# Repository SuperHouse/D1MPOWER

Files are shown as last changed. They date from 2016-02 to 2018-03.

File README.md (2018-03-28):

Power Shield for the WeMos D1 Mini
==================================

Copyright 2016 SuperHouse Automation Pty Ltd  www.superhouse.tv  

Power supply expansion shield for the [WeMos D1 Mini][1], which is a microcontroller board based on the ESP8266 module.

Features:

 * 2.1mm DC jack and screw terminal connections for power input.
 * 5Vdc output, max 800mA.
 * 7-14Vdc nominal input range, 20Vdc max input.
 * Input polarity protection.
 * Power LED.
 * Filter caps.

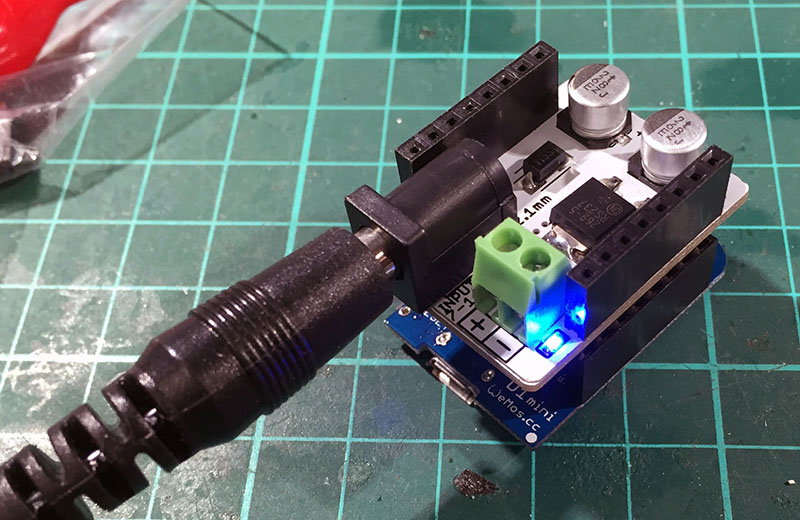
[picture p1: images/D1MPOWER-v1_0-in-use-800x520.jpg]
Oblique view 1


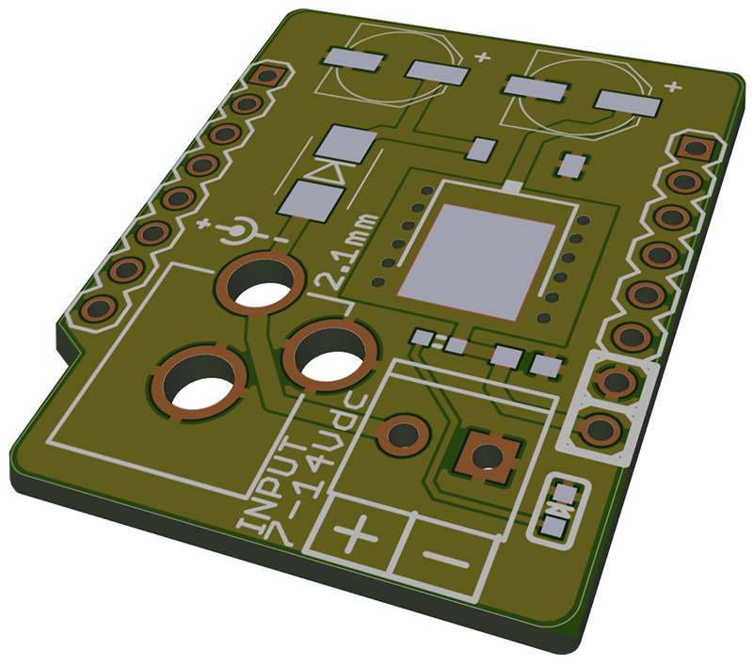
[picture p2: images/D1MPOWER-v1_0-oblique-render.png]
Oblique view 2


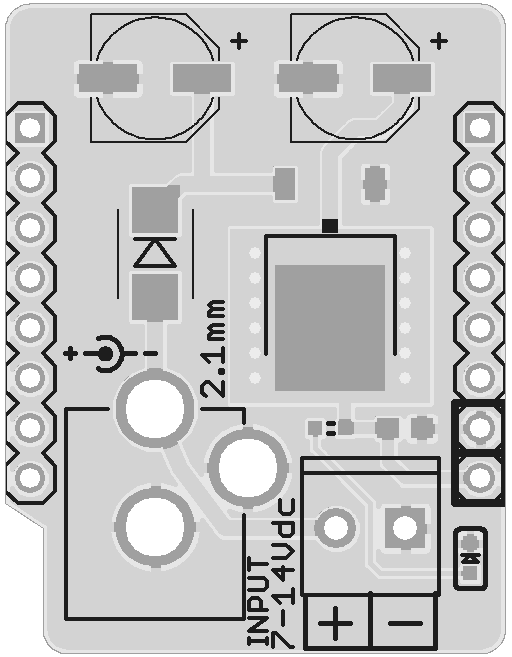
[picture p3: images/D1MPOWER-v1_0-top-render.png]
Top view


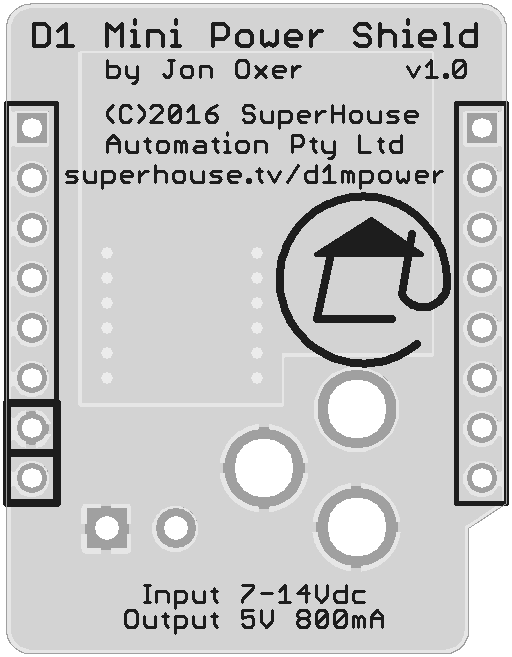
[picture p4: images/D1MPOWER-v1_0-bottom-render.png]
Bottom view


More information is available at:

  http://www.superhouse.tv/d1mpower

INSTALLATION
------------
The design is saved as an EAGLE project. EAGLE PCB design software is
available from www.cadsoftusa.com free for non-commercial use. To use
this project download it and place the directory containing these files
into the "eagle" directory on your computer.

DISTRIBUTION
------------
The specific terms of distribution of this project are governed by the
license referenced below.

LICENSE
-------
Licensed under the TAPR Open Hardware License (www.tapr.org/OHL).
The "license" folder within this repository also contains a copy of
this license in plain text format.

[1]: http://www.wemos.cc/wiki/doku.php?id=en:d1_mini

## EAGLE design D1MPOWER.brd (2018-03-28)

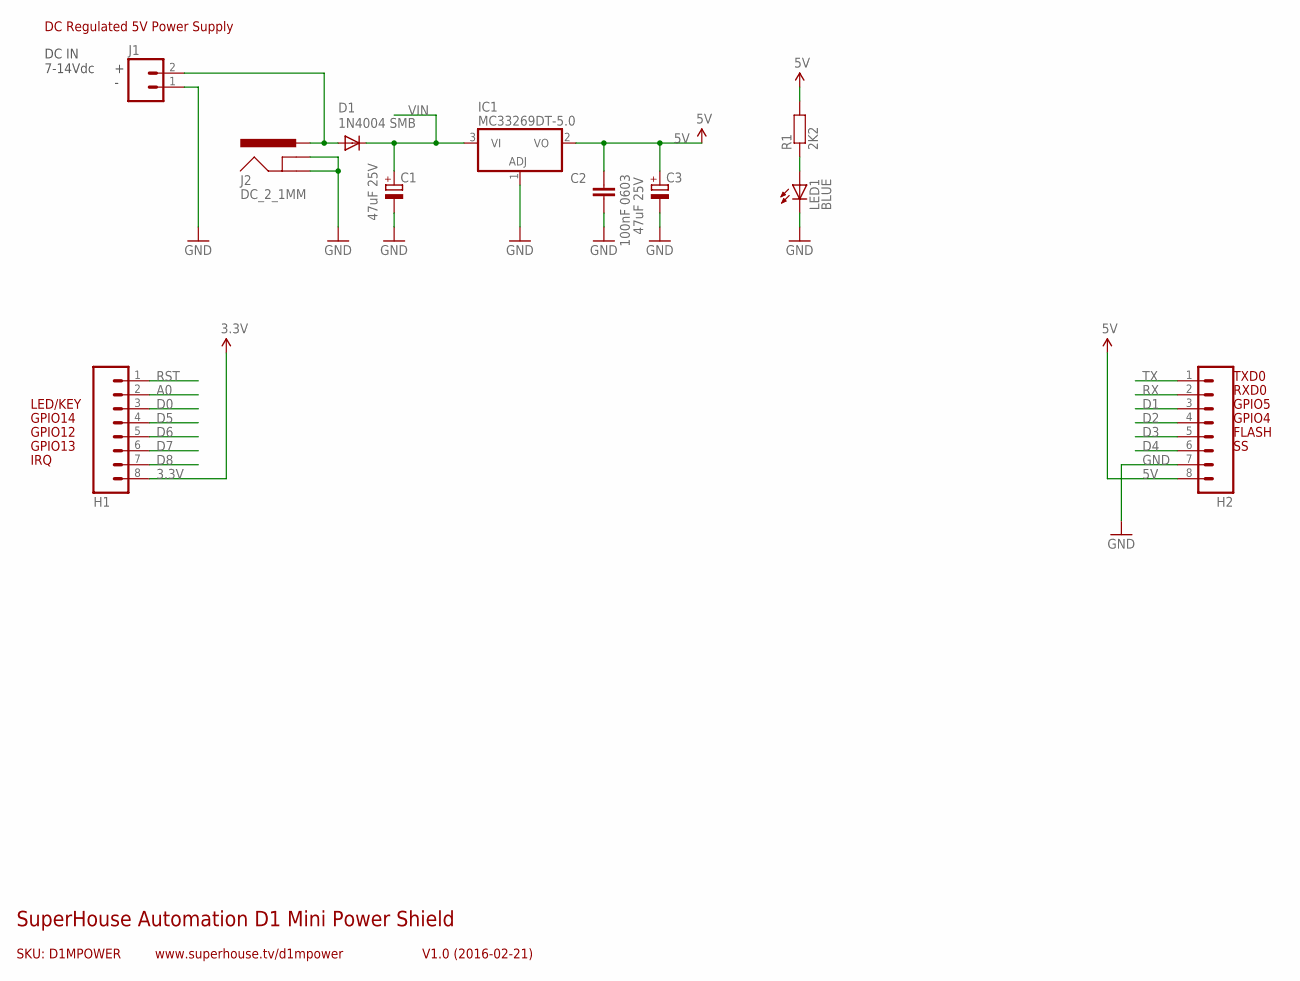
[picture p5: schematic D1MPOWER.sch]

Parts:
C1, C3: 47uF 25V; PANASONIC_D
C2: 100nF 0603; 0603
D1: 1N4004 SMB; SMB-DIODE
H1, H2: M08; 1X08
IC1: MC33269DT-5.0; DPACK
J1: M023.5MM; SCREWTERMINAL-3.5MM-2
J2: DC_2_1MM; POWER_JACK_PTH
LED1: BLUE; LED-0603
R1: 2K2; 0603

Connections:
3.3V: H1.8
5V: C2.1, C3.+, H2.8, IC1.2 (VO), R1.2
A0: H1.2
D0: H1.3
D1: H2.3
D2: H2.4
D3: H2.5
D4: H2.6
D5: H1.4
D6: H1.5
D7: H1.6
D8: H1.7
GND: C1.-, C2.2, C3.-, H2.7, IC1.1 (ADJ), J1.1, J2.GND, J2.GNDBREAK, LED1.C
unnamed: LED1.A, R1.1
unnamed: D1.A, J1.2, J2.PWR
RST: H1.1
RX: H2.2
TX: H2.1
VIN: C1.+, D1.C, IC1.3 (VI)

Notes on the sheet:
FLASH
GPIO12
GPIO4
GPIO5
RXD0
TXD0
GPIO13
GPIO14
IRQ
LED/KEY
SKU: D1MPOWER
SuperHouse Automation D1 Mini Power Shield
V1.0 (2016-02-21)
www.superhouse.tv/d1mpower
DC Regulated 5V Power Supply
DC IN 7-14Vdc

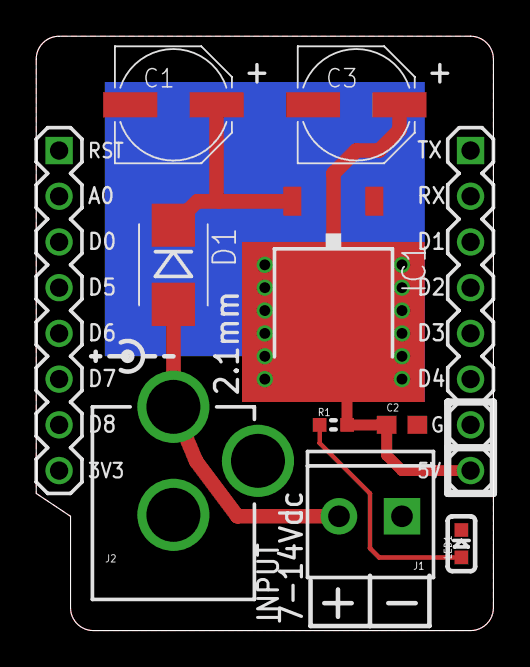
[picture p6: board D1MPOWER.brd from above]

Board: 2 copper layers, 25.4 x 33.0 mm, 11 parts (0 on the bottom side), 5 nets.

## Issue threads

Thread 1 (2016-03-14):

A shield based on the potted 240V power supply?

martyvis, 2016-03-14:
Have you considered making a D1 mini shield based on a small potted power supply such as http://www.aliexpress.com/item/Free-shipping-2pcs-lot-AC-DC-220V-to-5V-mini-power-supply-module-HLK-PM01/32610774236.html ?

Maybe add a PTC fuse and a varistor or two and it would be a nice way to embed a Wemos mini in appliances and the like. I guess safety is an issue the shield can be fully enclosed in a simple matchbox like insulated box to provide a full barrier from the HV?

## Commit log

2016-02-26 Initial import
    [D1MPOWER.brd, D1MPOWER.sch]
2016-02-29 Optimised part designators
    [D1MPOWER.brd, D1MPOWER.sch]
2018-03-28 Improvements to labels and images
    [D1MPOWER.brd, D1MPOWER.sch]

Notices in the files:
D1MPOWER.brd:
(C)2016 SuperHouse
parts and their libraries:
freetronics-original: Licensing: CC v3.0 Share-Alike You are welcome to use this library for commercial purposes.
